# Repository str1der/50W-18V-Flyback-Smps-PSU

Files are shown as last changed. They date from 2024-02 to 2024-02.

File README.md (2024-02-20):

# 50W 18V Smps Power Supply

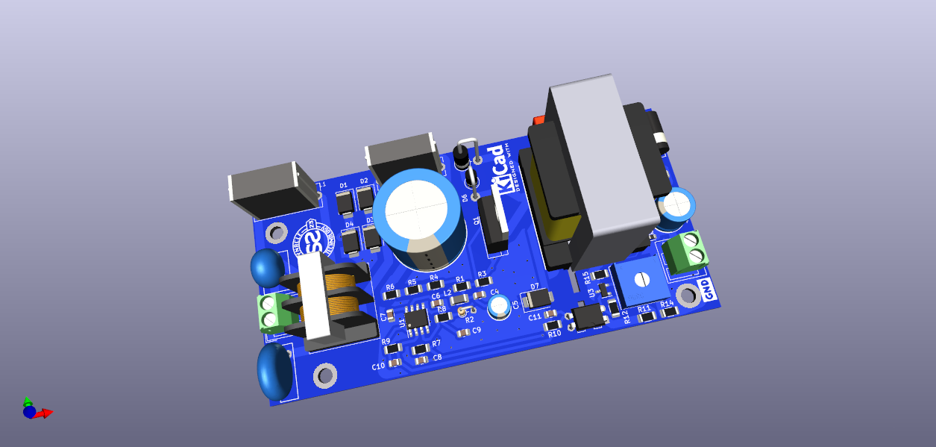
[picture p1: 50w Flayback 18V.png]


Bir Smps Trafo tasarımı ile ilgili tüm hesaplama ve detaylar "./Documents/SMPS Documents.pdf" dosyasında mevcuttur. 

https://github.com/str1der/50W-18V-Smps-PSU/blob/main/BOM/BOM.csv

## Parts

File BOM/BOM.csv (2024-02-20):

Reference | Value | Footprint | Datasheet | Sim.Device | Sim.Library | Sim.Name | Sim.Params | Sim.Pins | Qty
C1 | 150nF 305VAC | Capacitor_THT:C_Rect_L16.5mm_W6.0mm_P15.00mm_MKT | ~ |  |  |  |  |  | 1
C2 | 68uF 400V | Capacitor_THT:CP_Radial_D18.0mm_P7.50mm | ~ |  |  |  |  |  | 1
C3 | 100nF 400V | Capacitor_THT:C_Rect_L9.0mm_W3.2mm_P7.50mm_MKT | ~ |  |  |  |  |  | 1
C4, C7, C10, C11 | 100nF 25V | Capacitor_SMD:C_0805_2012Metric | ~ |  |  |  |  |  | 4
C5 | 47uF 50V | Capacitor_THT:CP_Radial_D8.0mm_P5.00mm | ~ |  |  |  |  |  | 1
C6, C13 | 1uF 25v | Capacitor_SMD:C_0805_2012Metric | ~ |  |  |  |  |  | 2
C8 | 2.2nF 50V | Capacitor_SMD:C_1206_3216Metric | ~ |  |  |  |  |  | 1
C9 | 220pF 50V | Capacitor_SMD:C_1206_3216Metric | ~ |  |  |  |  |  | 1
C12 | 470uF 25V | Capacitor_THT:CP_Radial_D8.0mm_P5.00mm | ~ |  |  |  |  |  | 1
D1-D4 | S2G | Diode_SMD:D_SMB | https://www.onsemi.com/pub/Collateral/US2AA-D.PDF | D |  |  |  | 1=K 2=A | 4
D5 | P6KE200A | Diode_THT:D_DO-15_P3.81mm_Vertical_AnodeUp | ~ |  |  |  |  |  | 1
D6 | UF4007 | Diode_THT:D_DO-41_SOD81_P3.81mm_Vertical_AnodeUp | ~ | D |  |  |  | 1=K 2=A | 1
D7 | ES2D | Diode_SMD:D_SMB | ~ | D |  |  |  | 1=K 2=A | 1
D8 | SB5100L | Diode_THT:D_DO-27_P12.70mm_Horizontal | ~ | D |  |  |  | 1=K 2=A | 1
J1, J2 | Screw_Terminal_01x02 | Connector_Wago:Wago_734-132_1x02_P3.50mm_Vertical | ~ |  |  |  |  |  | 2
L1 | 28mH 2A | Common_mode:SQ1515 | http://www.meisongbei.com/res/meisongbei/pdres/202111/flat_wire_choke_SQ1515.pdf |  |  |  |  |  | 1
L2 | 100R 100MHz | Inductor_SMD:L_1206_3216Metric | ~ |  |  |  |  |  | 1
Q1 | 6N60N | Package_TO_SOT_THT:TO-220-3_Vertical | https://pdf.direnc.net/upload/6n60-datasheet.pdf |  |  |  |  |  | 1
R1 | 33R 1/4W | Resistor_SMD:R_1206_3216Metric | ~ |  |  |  |  |  | 1
R2 | 0.33R 1/4W | Resistor_THT:R_Axial_DIN0204_L3.6mm_D1.6mm_P2.54mm_Vertical | ~ |  |  |  |  |  | 1
R3 | 10K 1/4W | Resistor_SMD:R_1206_3216Metric | ~ |  |  |  |  |  | 1
R4-R6, R9 | 100K 1/4W | Resistor_SMD:R_1206_3216Metric | ~ |  |  |  |  |  | 4
R7 | 3.3k 1/4W | Resistor_SMD:R_1206_3216Metric | ~ |  |  |  |  |  | 1
R8, R10 | 1k 1/4W | Resistor_SMD:R_1206_3216Metric | ~ |  |  |  |  |  | 2
R11, R14 | 680R 1/4W | Resistor_SMD:R_1206_3216Metric | ~ |  |  |  |  |  | 2
R12 | 4.7k 1/4W | Resistor_SMD:R_1206_3216Metric | ~ |  |  |  |  |  | 1
R13 | 2.2k 1/4W | Resistor_SMD:R_1206_3216Metric | ~ |  |  |  |  |  | 1
RV1 | TVR07471K | Varistor:RV_Disc_D9mm_W6.1mm_P5mm | ~ | SUBCKT | ${KICAD7_SYMBOL_DIR}/Simulation_SPICE.sp | kicad_builtin_varistor | threshold=1k | 1=A 2=B | 1
RV2 | 4.7k | Potentiometer_THT:Potentiometer_Bourns_3339W_Horizontal | ~ |  |  |  |  |  | 1
T1 | EE30 0.33mH 50W |  |  |  |  |  |  |  | 1
TH1 | KLS6-MF72-20D11 | Varistor:RV_Disc_D12mm_W3.9mm_P7.5mm | ~ |  |  |  |  |  | 1
U1 | UC3842_SOIC8 | Package_SO:SOIC-8_3.9x4.9mm_P1.27mm | http://www.ti.com/lit/ds/symlink/uc3842.pdf |  |  |  |  |  | 1
U2 | PC817 | Package_DIP:DIP-4_W7.62mm | http://www.soselectronic.cz/a_info/resource/d/pc817.pdf |  |  |  |  |  | 1
U3 | TL431 | Package_TO_SOT_SMD:SOT-23-5 | http://www.ti.com/lit/ds/symlink/tl431.pdf |  |  |  |  |  | 1

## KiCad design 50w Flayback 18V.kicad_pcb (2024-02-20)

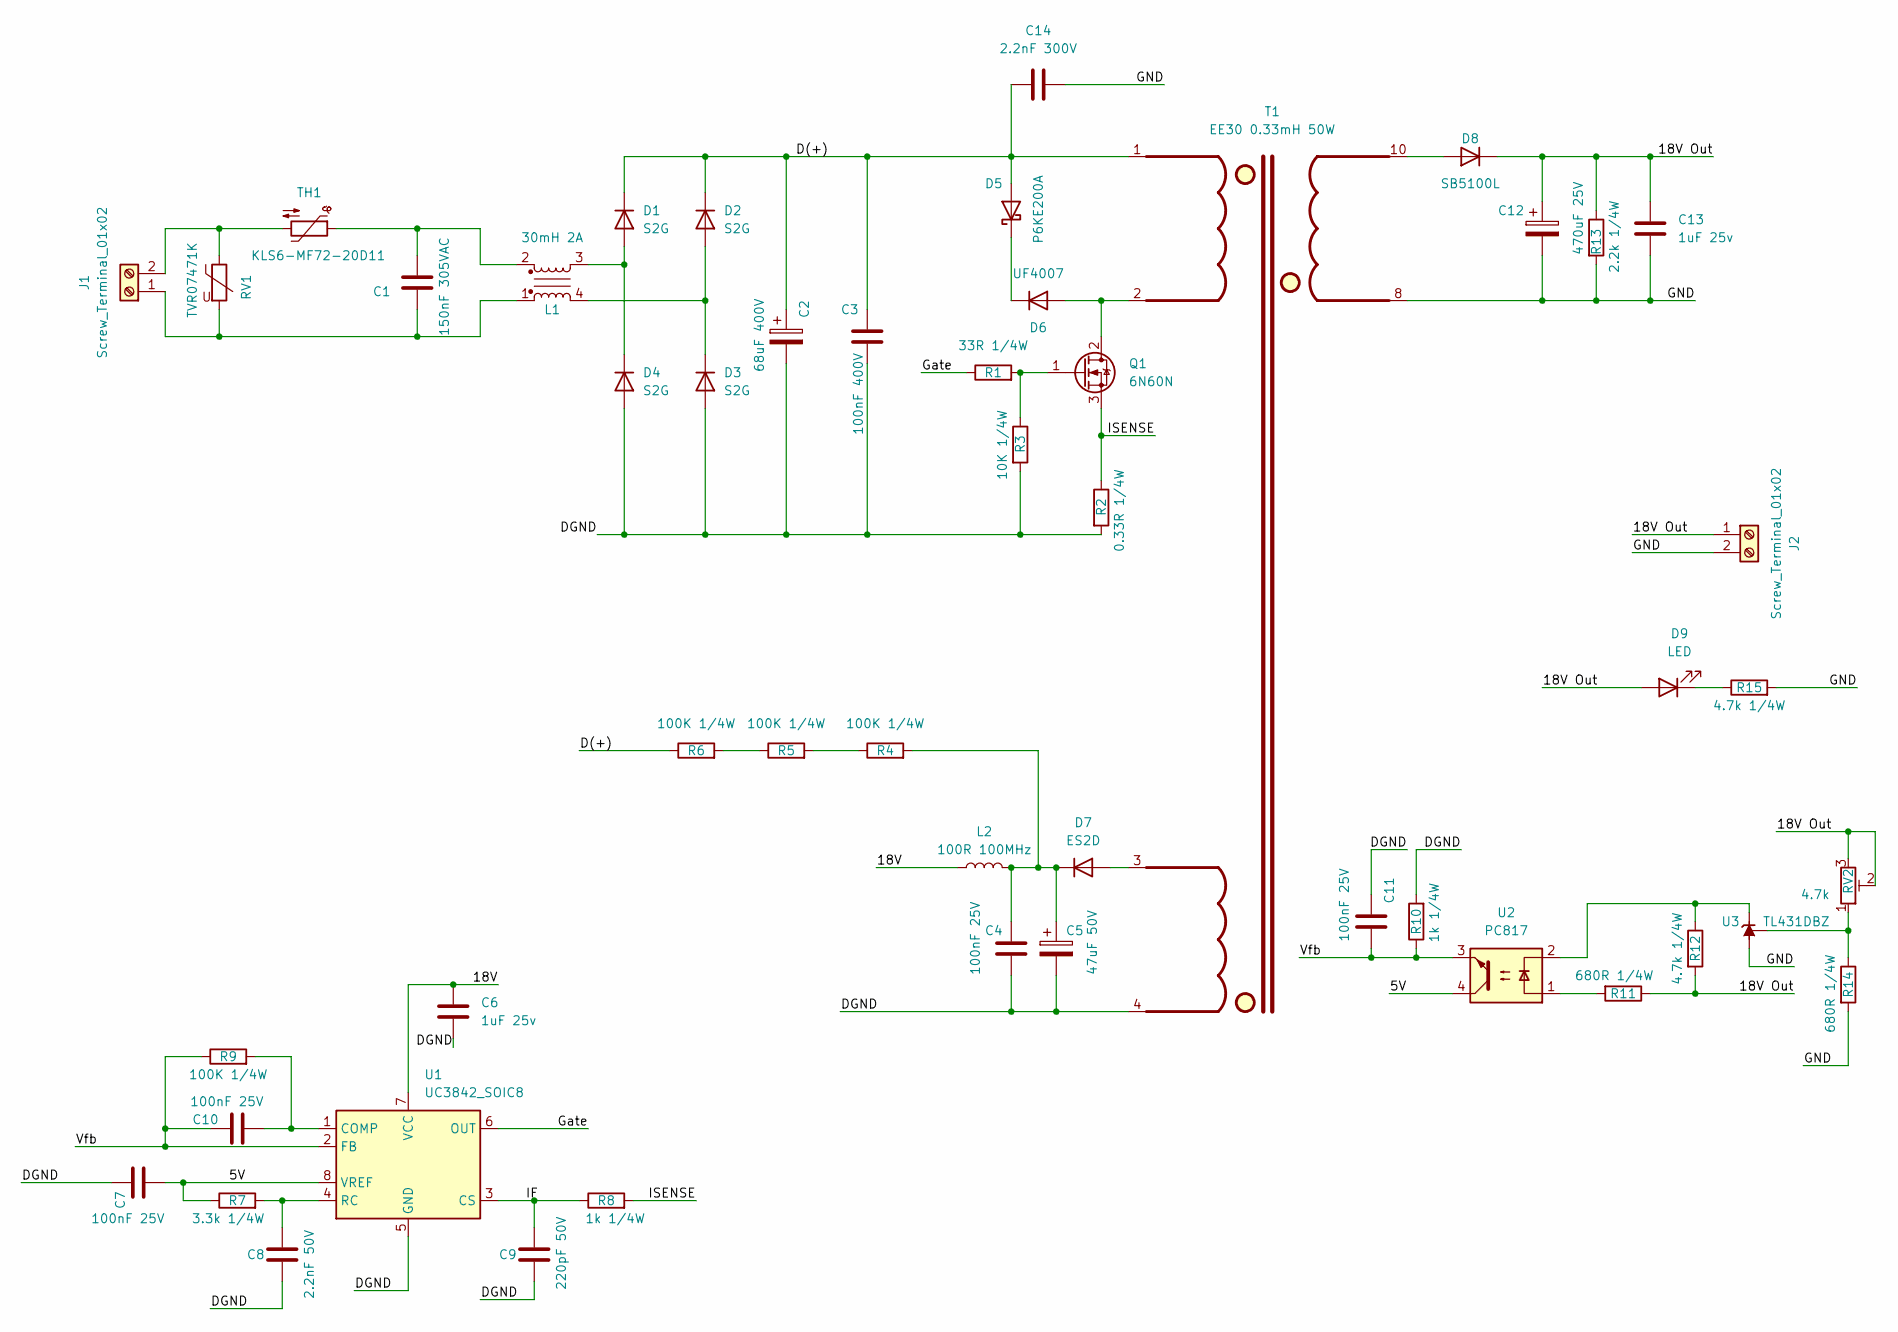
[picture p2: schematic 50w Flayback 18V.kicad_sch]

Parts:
C1: 150nF 305VAC; C_Rect_L16.5mm_W6.0mm_P15.00mm_MKT
C2: 68uF 400V; CP_Radial_D18.0mm_P7.50mm
C3: 100nF 400V; C_Rect_L16.5mm_W4.7mm_P15.00mm_MKT
C4, C7, C10, C11: 100nF 25V; C_0805_2012Metric
C5: 47uF 50V; CP_Radial_D5.0mm_P2.50mm
C6, C13: 1uF 25v; C_0805_2012Metric
C8: 2.2nF 50V; C_0805_2012Metric
C9: 220pF 50V; C_0805_2012Metric
C12: 470uF 25V; CP_Radial_D8.0mm_P5.00mm
C14: 2.2nF 300V; C_Rect_L13.0mm_W4.0mm_P10.00mm_FKS3_FKP3_MKS4
D1, D2, D3, D4: S2G; D_SMB
D5: P6KE200A; D_DO-15_P3.81mm_Vertical_AnodeUp
D6: UF4007; D_DO-41_SOD81_P3.81mm_Vertical_AnodeUp
D7: ES2D; D_SMB
D8: SB5100L; D_DO-27_P12.70mm_Horizontal
D9: LED; D_0603_1608Metric
J1, J2: Screw_Terminal_01x02; Wago_734-132_1x02_P3.50mm_Vertical
L1: 30mH 2A; UU10.5
L2: 100R 100MHz; L_1206_3216Metric
Q1: 6N60N; TO-220-3_Vertical
R1: 33R 1/4W; R_1206_3216Metric
R2: 0.33R 1/4W; R_Axial_DIN0204_L3.6mm_D1.6mm_P2.54mm_Vertical
R3: 10K 1/4W; R_1206_3216Metric
R4, R5, R6, R9: 100K 1/4W; R_1206_3216Metric
R7: 3.3k 1/4W; R_1206_3216Metric
R8, R10: 1k 1/4W; R_1206_3216Metric
R11, R14: 680R 1/4W; R_1206_3216Metric
R12, R15: 4.7k 1/4W; R_1206_3216Metric
R13: 2.2k 1/4W; R_1206_3216Metric
RV1: TVR07471K; RV_Disc_D9mm_W6.1mm_P5mm
RV2: 4.7k; Potentiometer_Bourns_3386F_Vertical
T1: EE30 0.33mH 50W; EE30-10pin
TH1: KLS6-MF72-20D11; RV_Disc_D12mm_W3.9mm_P7.5mm
U1: UC3842_SOIC8; SOIC-8_3.9x4.9mm_P1.27mm
U2: PC817; DIP-4_W7.62mm
U3: TL431DBZ; SOT-23

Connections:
/5V: C7.2, R7.1, U1.8 (VREF), U2.4
/18V: C6.1, L2.1, U1.7 (VCC)
/18V Out: C12.1, C13.1, D8.1 (K), D9.2 (A), J2.1, R11.1, R12.2, R13.1, RV2.2, RV2.3
/D(+): C2.1, C3.1, C14.1, D1.1 (K), D2.1 (K), D5.2 (A), R6.1, T1.1
/DGND: C2.2, C3.2, C4.2, C5.2, C6.2, C7.1, C8.2, C9.2, C11.2, D3.2 (A), D4.2 (A), R2.2, R3.2, R10.2, T1.4, U1.5 (GND)
/GND: C12.2, C13.2, C14.2, J2.2, R13.2, R14.2, R15.2, T1.8, U3.3 (A)
/Gate: R1.1, U1.6 (OUT)
/IF: C9.1, R8.1, U1.3 (CS)
/ISENSE: Q1.3 (S), R2.1, R8.2
/Vfb: C10.1, C11.1, R9.1, R10.1, U1.2 (FB), U2.3
unnamed: C1.1, L1.2, TH1.1
unnamed: D1.2 (A), D4.1 (K), L1.3
unnamed: D2.2 (A), D3.1 (K), L1.4
unnamed: D5.1 (K), D6.1 (K)
unnamed: D6.2 (A), Q1.2 (D), T1.2
unnamed: D7.2 (A), T1.3
unnamed: C4.1, C5.1, D7.1 (K), L2.2, R4.2
unnamed: D8.2 (A), T1.10
unnamed: D9.1 (K), R15.1
unnamed: C1.2, J1.1, L1.1, RV1.2
unnamed: J1.2, RV1.1, TH1.2
unnamed: Q1.1 (G), R1.2, R3.1
unnamed: R4.1, R5.2
unnamed: R5.1, R6.2
unnamed: R11.2, U2.1
unnamed: C10.2, R9.2, U1.1 (COMP)
unnamed: C8.1, R7.2, U1.4 (RC)
unnamed: R12.1, U2.2, U3.1 (K)
unnamed: R14.1, RV2.1, U3.2 (REF)

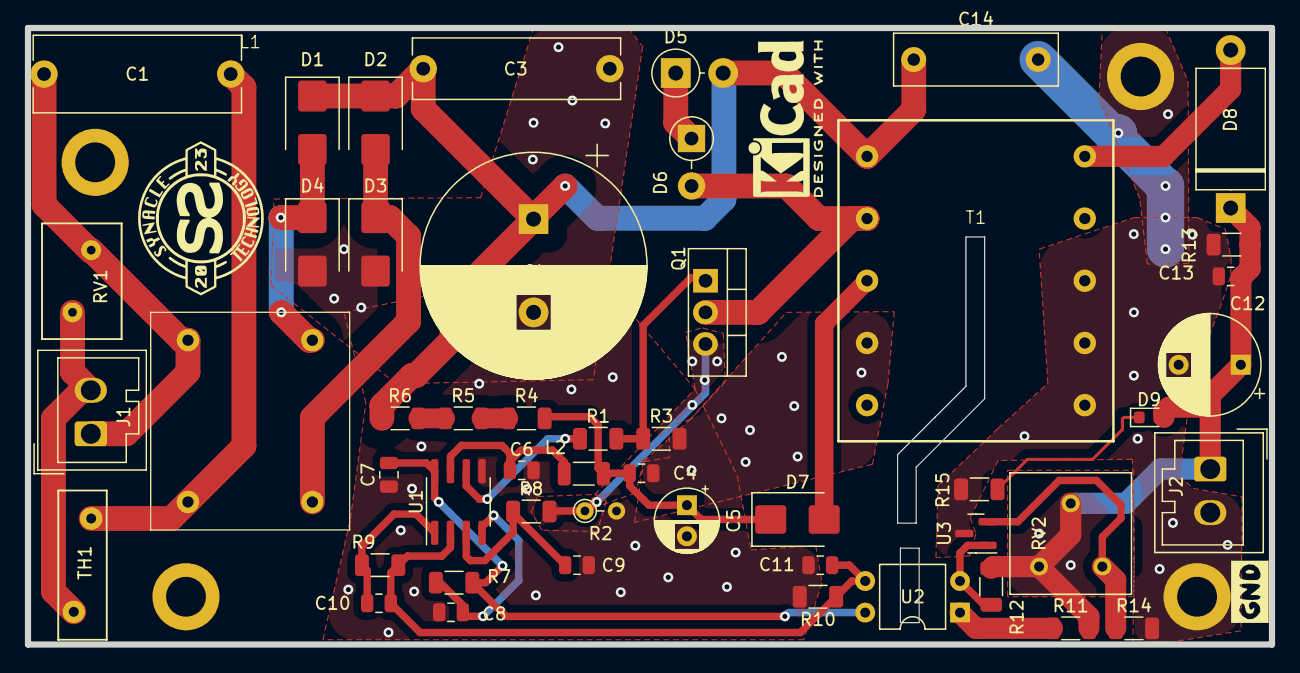
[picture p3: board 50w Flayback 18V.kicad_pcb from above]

Board: 2 copper layers, 100.0 x 49.6 mm, 50 parts (0 on the bottom side), 29 nets.
